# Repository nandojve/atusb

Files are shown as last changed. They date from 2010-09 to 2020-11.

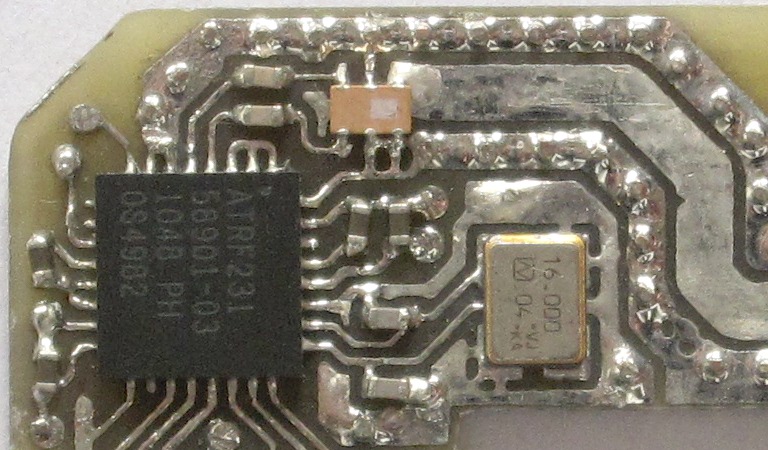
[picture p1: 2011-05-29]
prod/doc/atben-compor.jpg

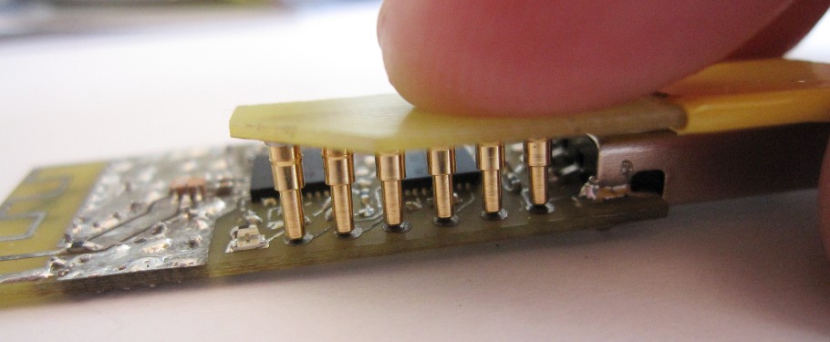
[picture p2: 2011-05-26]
prod/doc/atusb-programming.jpg

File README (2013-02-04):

IEEE 802.15.4 Low-Rate Wireless Personal Area Network (WPAN)
============================================================

IEEE 802.15.4 defines physical layers and a media access control for
wireless networks. ZigBee and 6loWPAN are based on IEEE 802.15.4.

This project aims to add experimental WPAN functionality to the Ben
NanoNote, in order to permit evaluation of overall network performance
and to examine possible integration into future devices.

This work is licensed under the terms detailed in the file COPYING.

Hardware history
----------------

IEEE 802.15.4 transceiver chips are available from several manufacturers,
including Atmel, Freescale, and Texas Instruments. These chips are similar
in size, functionality, and cost. The first prototype of this project was
based on the Atmel AT86RF230.

The initial plan was to place the RF module on the left side of the LCD
module of the Ben NanoNote, replacing part of the display's PCB. When
installed in the Ben, the transceiver would connect directly via SPI to
the Jz4720. For development, a SiLabs C8051F326 microcontroller
implemented a USB to SPI conversion.

Then Rikard Lindstrom came up with the idea of using the Ben's 8:10 card
slot as a general expansion interface, which led to the idea of making
a WPAN card in that form factor, with the benefit of being readily usable
with any Ben already in existence.

Thus the project was split in two parts: the atben card that had only the
transceiver chip and would be used with the Ben, and the atusb card that
would be similar to the original design but abandoned its clear physical
separation of USB and RF.

Meanwhile, an improved version of the AT86RF230, the AT86RF231, became
available and the designs were updated for it. It also turned out that
the clock from the Ben was too noisy to be used as a clock source for
the transceiver. Therefore, a crystal was added to the atben design.

Finally, the SiLabs C8051F326 was replaced by an ATmega32U2, mainly
because the latter has a larger Flash memory and greater community
acceptance.

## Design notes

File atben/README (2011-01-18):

PCB manufacturing:

- do not print PCB edges on front/back copper
- do not print component values on silk screen
- note that the transceiver is "upside down"
- the center (!) of the board edge line marks the true board edge, e.g.,

                             Edge line (5 mil)
                        =======
         ------- - - - - - ----------
               |           |
   PCB outside |           | PCB inside
               |           |
         ------- - - - - - ----------
                     |
               Volume removed when cutting
               (width depends on tool used)

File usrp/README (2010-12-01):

Antenna measurements
====================

The objective of antenna measurements is to determine how much energy the
antenna transfers at different frequencies. For this, we set up a sender,
a receiver, connect one to the antennas being tested, and the other to an
arbitrarily chosen lab antenna.

Since none of the items (sender, receiver, lab antenna) are calibrated,
we can only compare antennas but we cannot determine any absolute
characteristics.

Preparing a measurement run
---------------------------

Before measuring the characteristics of an antenna, we need to set up the
test environment and obtain a number of filtering parameters. The filters
are used to reduce the effect of noise on the measurements and to suppress
contamination from other sources.

1) Install transmitter and receiver. The transmitter is an atusb or atusd
   board, the receiver an USRP2+XCVR2450 with the antenna to test.

   (The same setup may also work with a USRP1 or UN210, and a RFX2400
   board.)

   Both should be spaced at least twenty times the wavelength (12.5 cm at
   2405 MHz), or 2.5 m apart. For test runs that can be compared with each
   other, antenna placement and orientation have to be exactly the same.

   The sender runs tools/atrf-txrx/atrf-txrx, the receiver runs utilities
   from gnuradio.

2) Obtain baseline performance values. For example, activate the sender
   with

   atrf-txrx -f 2455 -p 0.5 -T +0.5

   Emit a constant wave at 2455+0.5 MHz with a power of 0.5 dBm or 1.1 mW.

   Monitor the received signal with

   usrp2_fft.py -f 2455.5M -d 16

   Record the range in which the frequency peak falls. Variations of a few
   dB are to be expected.

3) Generate a series of sample for a specific setting.

   Example:

   The following script sets up the transmitter, lets it "warm up" for ten
   seconds, then takes 100 measurements, stored in files tmp00 through
   tmp99 in a directory $PWD/100/.

   In this setup, the receiver's gnuradio runs on a different host than
   the sender. Therefore we use ssh and pass the directory from $PWD.

    atrf-txrx -f 2455 -p 2.6 -T +0.5 \
      'sleep 10;
       for a in 0 1 2 3 4 5 6 7 8 9; do
         for b in 0 1 2 3 4 5 6 7 8 9; do
           ssh ws usrp2_rx_cfile.py -d 16 -f 2455.5M -g 46 -N 1124 \
	     '$PWD'/100/tmp$a$b
         done
       done'

   Each measurement obtains 1124 samples, 1024 samples for the FFT and
   100 samples to cut off (see below).

4) Determine the shape of the captured waves in the time domain, e.g.,
   with

   gnuplot
   gnuplot> plot "<./avg 1 <100/tmp00" with lines

   "avg" outputs the magnitude of the recorded wave, averaging over the
   specified number of sample.

   Some waves will probably show a peak in the first few samples. We need
   to cut off these peaks in the later processing steps. In this example,
   we will skip the first 100 samples.

   Besides the initial peak, the waves should be of comparable amplitude.

5) Verify the distribution in the frequency domain and determine the noise
   floor.

   gnuplot> plot "<./fft -s 100 -d <100/tmp00" with lines
                             ^
                          skip initial peak

   The spectrum should be U-shaped, with narrow peaks tens of dB above
   the noise floor near the beginning and the end. Note that the noise
   floor is curved and not perfectly flat.

   From this, we pick level of the noise floor. The value should be at or
   slightly below the highest peaks of the noise between the large peaks
   at the end of the spectrum.

   This noise floor value is used to filter uninteresting samples later
   on, removing a constant bias from the results.

   In this example, we'll use a noise floor value of -60 dB.

6) Determine the "interesting" frequency range. For this, we consider all
   the spectra of the measurements:

   gnuplot> plot "<for n in 100/tmp*; do ./fft -s 100 -d <$n;echo;done" \
     with lines

   There should be a thick noise band in the middle, with pronounced
   narrow peaks at the edges. If there are one or two signals on top of
   the noise band, some measurements have been compromised and need to be
   removed or redone. We will do this in the next step.

   When zooming into the left peak, the "bins" which contribute to the
   peaks can be identified. The range should be chosen with some
   tolerance, since the frequency may shift a bit during the measurement
   process.

   By not considering bins far from the peak, less noise is included in
   the final result, complementing the filtering by noise threshold from
   step 4). Restricting the bins also eliminates the second peak at the
   end of the spectrum.

   In this example, we'll use a range from 0 to 20.

7) Obtain the peaks from all measurements

   gnuplot> plot "<for n in 100/tmp*; do ./fft -s 100 0 20 60 <$n;done" \
     with lines
                                                   ^  ^  ^ ^
                                                   |  |  | |
                                   skip, from step 4  |  | threshold, 5)
                                             lowest bin  highest bin

   This should yield a jagged more or less horizontal line with values
   differing by not more than 1-2 dB. If there are any large outliers,
   they have been contaminated and should be dropped.

8) The final result for one measurement run can be obtained as follows:

   for n in 100/tmp*; do ./fft -s 100 0 20 60 <$n;done | ./range -v 2

   In this example, "range" eliminates all outliers more than 2 dB from
   the average and reports this.

   The output are three numbers: the average (after eliminating
   outliers), the minimum, and the maximum.

Performing a measurement run
----------------------------

The script "fscan" performs 100 scans of the 26 channels used by IEEE
802.15.4. The frequency scan is the inner loop, so that slow changes
in environmental parameters (background noise, temperature, etc.) will
affect the spread of the results over the entire frequency range instead
of causing seemingly frequency-dependent distortions.

The script is written for a setup that uses a pair of hosts, both
sharing the same file system.

Usage: fscan out-dir [tx-power]

The output directory must not exist yet. The transmit power is in dBm and
defaults to 2.6 dBm.

Example: ./fscan testant

The full run takes approximately half an hour.

The results are filtered and averaged by the script "evscan". This script
contains the filtering parameters obtained in the preparation, described
above.

Example: ./evscan testant >testant.out

The output is a graph with frequency, average signal strength, minimum
and maximum. The format is compatible with gnuplot's "with errorbars"
(or "with errorlines") plot style.

Finally, the results can be plotted with the script "plscan", which uses
gnuplot to output either in a window or to a PNG file.

Usage: plscan [-o pngfile] file ...

More than one graph can be plotted in the same run. The file name is used
as the title for each graph. Titles are truncated at the last dot.

Example: ./plscan testant.out

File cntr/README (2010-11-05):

Arbitrary-precision frequency counter
=====================================

Theory of operation
-------------------

The arbitrary-precision frequency counter counts clock cycles of a
frequency source that is assumed to be free from drift. It compares the
count with the host's system clock. If the system clock is synchronized
with an accurate NTP reference, measurements with arbitrarily high
accuracy can be obtained.

In practice, this is limited by the the frequency source's drift and
the time one is willing to wait. If NTP maintains the system time
with an accuracy of +/- 100 ms, obtaining measurements with an
accuracy of +/- 1 ppm would take about 28 hours.

Additional error sources, such as the round-trip time when requesting
a sample from the microcontroller, are also considered in the accuracy
calculation.

The counter consists of a board based on a C8051F320 microcontroller
and the control software on the host. The microcontroller counts
events in a free-running 16 bit counter that is regularly read and
extended to 32 bits. The 32 bit counter is periodically queried by
the host.

The microcontroller's counter can count at a frequency of up to 3 MHz.
(SYSCLK/4)

In order to protect against transmission errors not detected by USB's
CRC, which are occur relatively often, each packet is protected by a
CRC-32 and an inverted copy of the payload. Corrupted packets are
rejected by the host.

The 32 bit counter wraps around at most once very 21.8 ms. The 32 bit
counter wraps around at most every 1431 s. The host extends the 32 bit
counter to 64 bits, and calculates frequency and accuracy from the
count and the run time of the measurement application.

Performing a measurement
------------------------

To perform a measurement, connect the CNTR board's probe input to the
clock source and then run the "cntr" application on the host. An
accuracy goal (in ppm) can be specified on the command line (see
below).

The host polls the microcontroller every 100 ms and displays the run
time (in seconds), the measured frequency, and the accuracy achieved
so far.

Measurements can be stopped by pressing ^C or by specifying an
accuracy goal. At the end, the total number of events counted and
communication statistics are displayed.

Updating the firmware
---------------------

The protocol revision and the build date of the firmware of the CNTR
board can be queried with "cntr -i".

To update the firmware, run
cntr -r; sleep 1 && dfu-util -d 0x20b7:0xcb72 -D cntr.bin

Known issues (version 2 hardware)
---------------------------------

- the input circuit does not perform well. See ECN0006 for details.
- the MMCX connector is hard to solder because of its large thermal
  capacitance and surface
- the lateral pads of the MMCX connector could be wider
- manufacturing tolerances can push the USB connector a bit inside
  the board, making its signal pins overshoot the pads
- the ground fill under the LED causes a secondary cathode contact
  (which is harmless on this case)

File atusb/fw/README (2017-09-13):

Requires a very recent toolchain, because ATmega32U2 is relatively new.

- Building:

  make

- Uploading the firmware to a Ben (for flashing with the atusb-pgm cable):

  make HOST=<hostname> upload

  Example:

  make HOST=ben upload

  HOST defaults to "jlime".

- Flashing the boot loader:

  Prerequisite: avrdude on the Ben.

  Disconnect the atusb board from USB. Insert the atusb-pgm connector into
  the Ben. Place the atusb-pgm adapter on the exposed contact pads of the
  atusb board and push it down. Then run

  make prog

  This takes about 30 seconds. If the programming fails with an error
  message like "Yikes!  Invalid device signature.", verify that the
  atusb-pgm board is properly connected and placed, then try again.

- Uploading the application:

  Prerequisite: dfu-util installed on the PC.

  Insert atusb into the PC, then run

  make dfu

  Note: since the boot loader resets the USB bus after timing out,
  this operation can fail with a message like "No DFU capable USB device
  found". Just retry, and it will eventually get through.

HULUSB notes:
-------------
To prepare and flash the firmware on a HULUSB device some additional steps are
needed;

avr-objcopy -O ihex -R .signature -R .fuse -R .eeprom hulusb.elf hulusb.hex
dfu-programmer at90usb1287 flash hulusb.hex
dfu-programmer at90usb1287 reset

--------------------------

Making the toolchain:

# patches according to
# http://www.avrfreaks.net/index.php?name=PNphpBB2&file=viewtopic&p=789527

# some gcc prerequisites

apt-get remove avr-libc gcc-avr binutils-avr
apt-get install libmpfr-dev libmpc-dev

# binutils

wget http://ftp.gnu.org/gnu/binutils/binutils-2.21.tar.bz2
tar xfj binutils-2.21.tar.bz2 
cd binutils-2.21
./configure --target=avr --disable-nls
make
make install

# gcc

wget http://ftpmirror.gnu.org/gcc/gcc-4.5.2/gcc-4.5.2.tar.bz2
wget -O gcc_452_avr.patch http://gcc.gnu.org/bugzilla/attachment.cgi?id=23050
tar xfj gcc-4.5.2.tar.bz2
cd gcc-4.5.2
patch -p1 -s <../gcc_452_avr.patch
mkdir obj-avr
cd obj-avr
../configure --target=avr --enable-languages=c \
    --disable-nls --disable-libssp --with-dwarf2
make
make install

wget http://download.savannah.gnu.org/releases/avr-libc/avr-libc-1.7.1.tar.bz2
tar xfj avr-libc-1.7.1.tar.bz2 
cd avr-libc-1.7.1
./bootstrap	# the automake at the end takes a while
./configure --build=`./config.guess` --host=avr
make
make install

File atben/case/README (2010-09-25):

You'll need a working Heekscad [1] to open the cad file provided,
all file are licended under GPLv3

In kicad export/generate the PCB as gerber, note the extension is not .brd by default so you'll need to 
fix it manually to heekcad "see it".

Copyleft 2010 Cristian Paul Peñaranda  Rojas paul@kristianpaul.org

[1] http://code.google.com/p/heekscad/

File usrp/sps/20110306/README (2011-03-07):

Objective:

Reproduce sidebands observed in 200110303 and look for ways to reduce them.
In particular, examine the effect of the antenna tuning capacitor C16.

Test setup / changes:

4	original board, like in 20110303 (noise from WLAN I forgot to turn off)
4a	reflowed some RF vias; cleaning
4b	removed large solder deposits on RF; not cleaned
4c	cleaning after 4b
4d	0.5 pF at C16; cleaning
4e	1.0 pF at C16; cleaning
4f	C16 NC; cleaning
4g	resolder pin B1.1; cleaning
4h	replace cracked B1; switched to leaded solder; cleaning
4i	reflowed B1 at higher temperature; cleaning
4j	reflowed C8's balun side; cleaning

3	original board, like in 20110303
3a	wait 2 h (warm-up; USRP2 freshly booted)
3b	cycle (unplug/plug) atusb
3c	retract shutters (metal)

-------------------------------------------------------------------------------

Observations:

4	behaves as it did in 20110303
4a	no change
4b	no change
4c	no change
4d	no change
4e	no change
4f	major regression
4g	regression persists
4h	regression persists (slight recovery seen in 4h-0 may be due to
	temporary effects)
4i	regression persists
4j	regression persists; giving up

3	behaves as it did in 20110303; significantly cleaner
3a	sidebands are reduced
3b	sideband reduction persists
3c	~10 dB drop at lower end of spectrum

-------------------------------------------------------------------------------

Conclusions:

- build quality seems to be principal factor in RF performance variations
- a warmed up board performs slightly better than a cold board
- C16 has no noticeable effect
- reflection characteristics even of distant items in the environment have
  a strong influence on relative signal strength

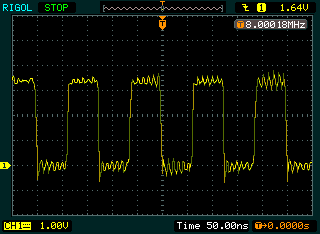
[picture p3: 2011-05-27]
prod/doc/scope-atusb-clkm.png

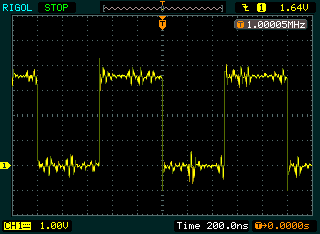
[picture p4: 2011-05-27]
prod/doc/scope-atben-clkm.png

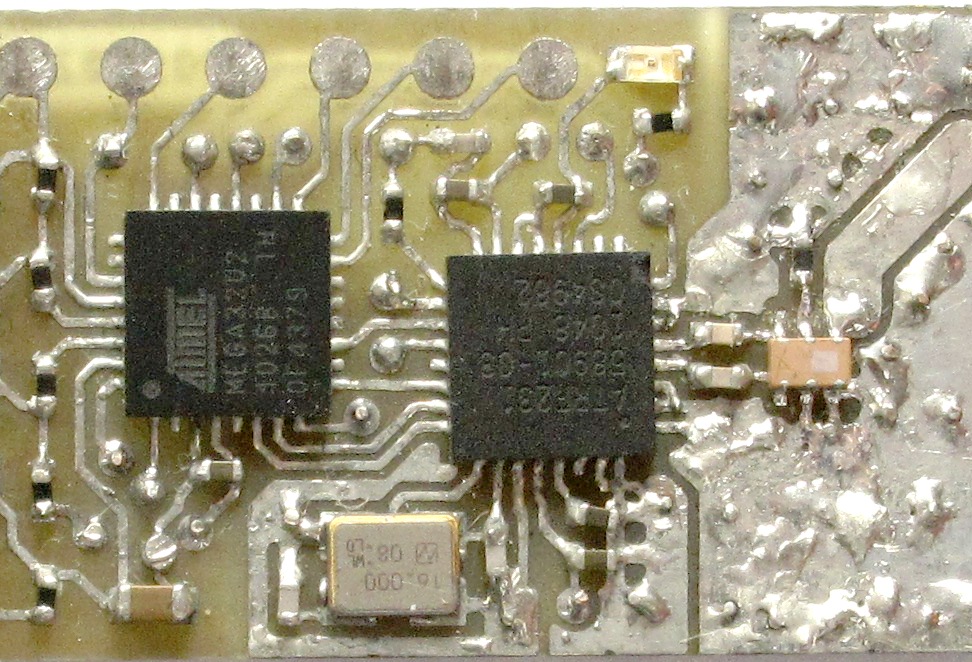
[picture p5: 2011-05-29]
prod/doc/atusb-compor.jpg

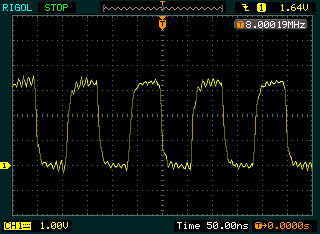
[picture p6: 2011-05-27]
prod/doc/scope-atusb-clk.png

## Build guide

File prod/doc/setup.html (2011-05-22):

# Production and testing: Software setup

Before performing any production tests, various pieces of software need to be installed on Ben and PC, and configuration settings @@@

## PC software installation

@@@

### Install ben-wpan tools

@@@

### Install test scripts

@@@

### Install firmware binary

The binary of the application running on atusb is transferred from the PC. To download a pre-compiled version, use this command:

wget -O atusb.bin \
     http://downloads.qi-hardware.com/people/werner/wpan/bindist/atusb-de72af351f661b538add81cbc9965278a2f8c40c.bin

Instructions for building the binary from sources are here (http://projects.qi-hardware.com/index.php/p/ben-wpan/source/tree/master/atusb/fw/README).

### Register Ben host name

To simplify accessing the Ben via TCP/IP, its IP address should be registered in the hosts file on the PC. If the Ben is running OpenWrt, use the following command:

echo 192.168.254.101 ben >>/etc/hosts

If the Ben is running Jlime, the address would be as follows:

echo 192.168.1.202 ben >>/etc/hosts

If using the same PC with Bens running OpenWrt and Jlime, one may choose different host names depending on the distribution, and adapt the commands used in the production and testing process accordingly. For example,

echo 192.168.254.101 ben >>/etc/hosts
echo 192.168.1.202 jlime >>/etc/hosts

### Customize test scripts

@@@

## Ben software installation

@@@

### Password-less remote access

To enable password-less remote access from the PC, set up network access to the Ben and run the following command:

ssh ben 'cat >>/etc/dropbear/authorized_keys' <~/.ssh/id_rsa.pub

### Install ben-wpan tools

@@@

### Install avrdude

The atusb boot loader is flashed using avrdude. A pre-compiled static binary (suitable for OpenWrt and Jlime) can be installed by running the following two command on the Ben:

wget http://downloads.qi-hardware.com/people/werner/wpan/bindist/avrdude-5.10-de72af351f661b538add81cbc9965278a2f8c40c.tar.gz
tar -xz -C / -f avrdude-5.10-de72af351f661b538add81cbc9965278a2f8c40c.tar.gz

Instructions for building avrdude from sources are here (http://projects.qi-hardware.com/index.php/p/ben-blinkenlights/source/tree/master/avrdude/README).

### Install boot-loader binary

The binary of the boot loader running on atusb is transferred from the Ben. To download a pre-compiled version, use this command:

wget -O boot.hex \
   http://downloads.qi-hardware.com/people/werner/wpan/bindist/boot-de72af351f661b538add81cbc9965278a2f8c40c.hex

Instructions for building the binary from sources are here (http://projects.qi-hardware.com/index.php/p/ben-wpan/source/tree/master/atusb/fw/README).

## Ben system setup

The configuration setting described in this section are lost on each reset or reboot and either need to be entered again. Alternatively, a setup script running at boot time can be written.

### Enable network access

Once the Ben has booted and started USB networking, the interface on the PC side is configured as follows:

ifconfig usb0 192.168.254.100 up

These are the settings for OpenWrt, assuming the network device is called "usb0". If using Jlime, the command would be as follows:

ifconfig usb0 192.168.1.200 up

### Silence other 8:10 card users

Before running any of the ben-wpan utilities, other users of the 8:10 card slot have to be disabled. In a Ben running the regular OpenWrt or Jlime distribution, the only such user that is automatically started is the MMC kernel driver. The following command disables it:

echo jz4740-mmc.0 >/sys/bus/platform/drivers/jz4740-mmc/unbind

If a WPAN-enabled kernel has been installed, the AT86RF230 driver takes the place of the MMC driver. To disable it, run

echo spi2.0 >/sys/bus/spi/drivers/at86rf230/unbind

### Start atrf-proxy

On the Ben, launch the proxy daemon. We pass the option -b to background it:

atrf-proxy -b

## Test profiles

Some of the functional tests measure characteristics that are strongly influenced by the test setup. It is therefore not possible to provide universally applicable reference values, but they have to be measured in the actual test environment.

### Clock count (atben only)

Insert a known to be good atben board and run the following command directly on the Ben to record the reference value for the clock count with an accuracy of about +/−20 ppm:

atrf-xtal 1000 >ben.xtal

This takes about 5 seconds.

Note that the result depends on the tolerance of the crystal in the Ben and is also affected by temperature. Good accuracy can therefore only be obtained if this measurement is performed individually on each Ben, and if a stable temperature is maintained.

### Signal strength

@@@

Up: Production and testing Next: Flashing (atusb only)

Last update: 2011-05-19 Werner Almesberger

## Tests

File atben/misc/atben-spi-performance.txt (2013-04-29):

Performance analysis of SPI drivers for ATBEN
=============================================

This was originally posted on April 10 2013 to the linux-zigbee and
the qi-hardware list. The URLs have been updated for stability.

Note that the code referenced in this analysis is meant to illustrate
the general concepts. Some variants have been dropped since and the
ones still in existence have been cleaned up and debugged in
preparation for upstream submission. The current versions can be
found in https://github.com/wpwrak/ben-wpan-linux

What this is all about
----------------------

The ATBEN board on the Ben NanoNote needs a bit-banging SPI driver.
There are several ways to implement this, ranging from reuse of the
generic spi-gpio driver to an optimized driver that's specific for
this platform.

I implemented several such approaches and measured their performance
in the Ben NanoNote. Below are my findings.

Comments welcome.

Cast and characters
-------------------

spi_atben_gpio: NanoNote-specific framework for setting up the
AT86RF230/1 with SPI-GPIO or one of the optimized drivers (below).
The name derives from spi_atben (see below) and should be changed
(maybe to atben_spi or atben_spi_gpio ?) since it is not an SPI
driver but merely a framework that provides configuration data and
performs miscellaneous platform setup.
https://github.com/wpwrak/ben-wpan-linux/blob/perfcomp/drivers/net/ieee802154/spi_atben_gpio.c

spi_atben: like spi_atben_gpio, but contains a highly optimized
SPI driver for the ATBEN configuration in the Ben NanoNote.
https://github.com/wpwrak/ben-wpan-linux/blob/perfcomp/drivers/net/ieee802154/spi_atben.c

spi-jz4740-gpio: SPI-GPIO driver optimized for the Jz4740. Uses the
optimized register accesses from spi_atben but pin assignment is not
restricted to ATBEN. The only limitation is that MOSI, MISO, and
SCLK must be on the same port.
https://github.com/wpwrak/ben-wpan-linux/blob/perfcomp/drivers/spi/spi-jz4740-gpio.c

spi-gpio-atben: task-specific SPI-GPIO driver using the #include
"spi-gpio.c" method. Replaces gpiolib functions with register
accesses specific to the ATBEN configuration in the Ben NanoNote.
Note that some of the code could be moved into Jz4740
architecture-specific GPIO support.
https://github.com/wpwrak/ben-wpan-linux/blob/perfcomp/drivers/spi/spi-gpio-atben.c

In the following sections, we abbreviate the stack configurations
as follows:

Abbreviation	Framework	Transport	Chip driver
---------------	---------------	---------------	-----------
spi-gpio	spi_atben_gpio	spi-gpio	at86rf230
spi-gpio-atben	spi_atben_gpio	spi-gpio-atben	at86rf230
spi-jz4740-gpio	spi_atben_gpio	spi-jz4740-gpio	at86rf230
spi_atben	spi_atben			at86rf230

Measurements
------------

Access time to AT86RF231 registers and buffer, in microseconds, on
an otherwise idle Ben NanoNote:

Driver		read from 0x51		read 120 bytes from buffer
|		|	write 0x0a to 0x15	write 1 byte to buffer (0x33)
|		|	|	read 1 byte from buffer	write 120 bytes
|		|	|	|	|	|	|
spi-gpio	 81	 85	186	1696	 97	1596
spi-gpio-atben	 63	 59	123	 498	 65	 437
spi-jz4740-gpio	 10	  8	 21	 280	 10	 231
spi_atben	 10	  7	 21	 280	 10	 230

Data rate for hypothetical buffer accesses of infinite length.
I.e., kbps = 1000*119*8/(t_write120-t_write1)

Driver		buffer read (kbps)	buffer write (kbps)
---------------	-----------------------	-------------------
spi-gpio	 630			 635			
spi-gpio-atben	2549			2559
spi-jz4740-gpio	3676			4308
spi_atben	3676			4327

At the air interface, IEEE 802.15.4 has a data rate of 250 kbps.
The AT86RF231 transceiver also supports non-standard higher data
rates up to 2 Mbps.

Driver(s)				Code size (lines)
---------------------------------------	-----------------
spi_atben_gpio				 128
spi_atben_gpio + spi-gpio-atben		 128+ 53
spi_atben_gpio + spi-jz4740-gpio	 128+416
spi_atben				 423

Computational cost
------------------

The high-level operations of sending and receiving produce the
following major low-level operations:

Operation	register	buffer		waitqueue
		read	write	read	write
---------------	-------	-------	-------	-------	---------
reception	1	-	1	-	1
transmission	9	4	-	1	1

Using the measured data from above, we get the following total
computational overhead in microseconds, without considering the
waitqueue scheduling delay:

Driver		reception		transmission
		1	120	127	1	120	125 (bytes)
---------------	-------	-------	-------	-------	-------	-------
spi-gpio	 267	1777	1866	1166	2665	2727
spi-gpio-atben	 186	 561	 583 	 868	1240	1256
spi-jz4740-gpio	  31	 290	 304 	 132	 353	 362

Note that the minimum frame length in IEEE 802.15.4 is 5 bytes.
The values for 125 (excluding CRC) and 127 (including CRC) bytes
are extrapolated.

According to [1], maximum-sized frames can be sent/received,
including CSMA/CA and acknowledgement, at a rate between one
every 4928 us and one every 7168 us.

We would therefore get the following maximum CPU load:

Driver		Reception	Transmission
---------------	---------------	------------
spi-gpio	38%		55%
spi-gpio-atben	12%		25%
spi-jz4740-gpio	 6%		 7%

Observations
------------

spi-gpio needs the smallest amount of new code but is also very
inefficient, making it questionable whether this configuration
would yield acceptable performance in regular use.

With spi-gpio-atben, only a small amount of code is added, but
buffer accesses become almost 4 times faster. Register reads and
writes are still fairly slow.

spi_atben and spi-jz4740-gpio both achieve the best performance
without significant differences between them. Both add a complete
SPI driver. Of the two, spi-jz4740-gpio is preferable, because it
uses the nearly universal spi_atben_gpio framework driver.

Conclusion
----------

I think performance trumps most other considerations in this case.
spi-gpio is clearly too inefficient. spi_atben_gpio with
spi-jz4740-gpio offers the best performance and has a low impact
on the system load (< 10%). In case this solution would be met
with strong resistance for some reason, spi-gpio-atben would offer
a compromise between performance and the amount of code.

References
----------

[1] http://www.jennic.com/files/support_files/JN-AN-1035%20Calculating%20802-15-4%20Data%20Rates-1v0.pdf

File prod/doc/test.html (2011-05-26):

# Production and testing: Functional test

## Test setup for atben

To test an atben board, place a reference atusb board into the PC, insert the



## Test setup for atusb



## Test procedure

The test process is started with

make ben

for an atben DUT and with

make usb

for an atusb DUT. It performs the following steps:

- Enumeration (atusb only)
- LED (atusb only; not yet implemented)
- GPIO scan (not yet implemented)
- Identification
- Crystal frequency (only implemented on atben)
- Spectrum
- Receive
- Send

Of these tests, only "LED" and "Spectrum" require operator input. The other tests run without interaction.

The test scripts log the commands they execute and their output in the file _log.

### Enumeration (atusb only)

The enumeration test verifies that the atusb board has been identified by the PC's USB stack. If this test fails, the board may not be plugged in correctly or it may be missing the firmware. A board that has passed both stages of the firmware flashing process should always pass the enumeration test.

### LED (atusb only)

@@@

### GPIO scan

@@@

### Identification

This test reads the transceiver's registers that contain values identifying the manufacturer, the chip's part number, and the chip revision. If an atusb board fails this test, this probably means that the MISO signal between transceiver and the microcontroller has a problem.

On atben, failure may simply indicate an improperly inserted board. Eject the board, re-insert, and try again. If the test keeps on failing, this may indicate a problem with MOSI, MISO, nSEL, SCLK, the power supply, the crystal oscillator, or possibly the position of the transceiver chip.

Note: this test is meant as a higher level test. The GPIO test should eventually provide more detailed results for problems with the SPI interface.

### Crystal frequency (atben only)

This test measures the frequency of the crystal oscillator in the DUT. On atben, it does this by transmitting packets, and measuring the time between the SLP_TR pulse that starts the transmission and the interrupt signaling the end of the transmission.

If this test fails, this may indicate that the load capacitors of the crystal are missing, badly soldered, or have the wrong value. It could also mean that the crystal itself is defective. Another possible cause of oscillator malfunction could be flux residues bridging traces.

The fault analysis page has more details on testing the crystal oscillator.

### Spectrum

The spectrum test measures the reception of a signal sent from the reference device to the DUT. It does this across the entire frequency range in which the WPAN boards operate, allowing the detection of frequency-dependent anomalies.

This test depends on numerous external factors, like the exact position and orientation of the two devices with respect to each other, and the presence of any items that can reflect or absorb RF signals. Such items include metal chairs and human bodies. Because of the test's sensitivity to environmental factors, the operator needs to decide when the result represents a valid measurement and then confirm the result shown.

The image below shows the typical display during the spectrum test: the white line is the measured signal strength. The red lines indicate the minimum and maximum allowed values. The green circle in the upper right corner indicates that the signal strength is within the limits. A downward-pointing red triangle would indicate that the signal is too weak, an upward-pointing yellow triangle would indicate that the signal is too strong.



To finish the test, the operator must type either P, F, or Q in the window shown. P means "pass" and can only be entered if the measurement is within the limits. F means "fail" and can only be entered if the measurements is outside the limits. Q, quit, can be entered at any time and also fails the test.

### Receive

In the receive test, the reference device sends a number of frames to the DUT. The test program verifies correct reception of all the frames. A device that has passed all the preceding tests should not encounter problems in the receive test. If it does, there may be a problem with the bypassing of the transceiver's 1.8 V supplies.

### Send

The send test is like the receive test, but with the DUT acting as the sender and the reference acting as the receiver. If a device passes the receive test but fails the send test, there is probably an issue with the bypass capacitors of the analog 1.8 V supply.

Another possible cause could a problem with the SLP_TR signal. The GPIO test should eventually catch this issue, but it may currently remain undetected until the send test.

Up: Production and testing Prev: Flashing (atusb only) Next: Fault analysis

Last update: 2011-05-26 Werner Almesberger

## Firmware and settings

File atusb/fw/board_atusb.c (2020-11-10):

/*
 * fw/board_atusb.c - ATUSB Board-specific functions (for boot loader and application)
 *
 * Written 2016 by Stefan Schmidt
 * Copyright 2016 Stefan Schmidt
 *
 * This program is free software; you can redistribute it and/or modify
 * it under the terms of the GNU General Public License as published by
 * the Free Software Foundation; either version 2 of the License, or
 * (at your option) any later version.
 */


#include <stdbool.h>
#include <stdint.h>

#include <avr/io.h>
#include <avr/interrupt.h>
#include <avr/boot.h>

#define F_CPU   8000000UL
#include <util/delay.h>

#include "usb.h"
#include "at86rf230.h"
#include "board.h"
#include "spi.h"
#include "usb/usb.h"

static bool spi_initialized = 0;

void reset_rf(void)
{
	/* set up all the outputs; default port value is 0 */

	DDRB = 0;
	DDRC = 0;
	DDRD = 0;
	PORTB = 0;
	PORTC = 0;
	PORTD = 0;

	OUT(LED);
	OUT(nRST_RF);   /* this also resets the transceiver */
	OUT(SLP_TR);

	spi_init();

	/* AT86RF231 data sheet, 12.4.13, reset pulse width: 625 ns (min) */

	CLR(nRST_RF);
	_delay_us(2);
	SET(nRST_RF);

	/* 12.4.14: SPI access latency after reset: 625 ns (min) */

	_delay_us(2);

	/* we must restore TRX_CTRL_0 after each reset (9.6.4) */

	set_clkm();
}

void led(bool on)
{
	if (on)
		SET(LED);
	else
		CLR(LED);
}

void set_clkm(void)
{
	/* switch CLKM to 0 MHz */

	/*
	 * @@@ Note: Atmel advise against changing the external clock in
	 * mid-flight. We should therefore switch to the RC clock first, then
	 * crank up the external clock, and finally switch back to the external
	 * clock. The clock switching procedure is described in the ATmega32U2
	 * data sheet in secton 8.2.2.
	 */
	spi_begin();
	spi_send(AT86RF230_REG_WRITE | REG_TRX_CTRL_0);
	spi_send(CLKM_CTRL_OFF);
	spi_end();
}

void board_init(void)
{
	/* Disable the watchdog timer */

	MCUSR = 0;		/* Remove override */
	WDTCSR |= 1 << WDCE;	/* Enable change */
	WDTCSR = 1 << WDCE;	/* Disable watchdog while still enabling
				   change */

	CLKPR = 1 << CLKPCE;
	/* We start with a 1 MHz/8 clock. Disable the prescaler. */
	CLKPR = 0;

	get_sernum();
}

void spi_begin(void)
{
	if (!spi_initialized)
		spi_init();
	CLR(nSS);
}

void spi_off(void)
{
	spi_initialized = 0;
	UCSR1B = 0;
}

void spi_init(void)
{
	SET(nSS);
	OUT(SCLK);
	OUT(MOSI);
	OUT(nSS);
	IN(MISO);

	UBRR1 = 0;	/* set bit rate to zero to begin */
	UCSR1C = 1 << UMSEL11 | 1 << UMSEL10;
			/* set MSPI, MSB first, SPI data mode 0 */
	UCSR1B = 1 << RXEN1 | 1 << TXEN1;
			/* enable receiver and transmitter */
	UBRR1 = 0;	/* reconfirm the bit rate */

	spi_initialized = 1;
}

void usb_init(void)
{
	UHWCON |= 1 << UVREGE;		/* Power-On USB pad regulator */
	USBCON |= 1 << FRZCLK;		/* freeze the clock */

	/* enable the PLL and wait for it to lock */
	PLLCSR &= ~(1 << PINDIV);
	PLLCSR |= 1 << PLLE;
	while (!(PLLCSR & (1 << PLOCK)));

	USBCON &= ~(1 << USBE);		/* reset the controller */
	USBCON |= 1 << USBE;

	USBCON &= ~(1 << FRZCLK);	/* thaw the clock */

	USBCON |= 1 << OTGPADE;

	while (!(USBSTA & (1 << VBUS)));

	UDCON &= ~(1 << DETACH);	/* attach the pull-up */
	UDIEN = 1 << EORSTE;		/* enable device interrupts  */
//	UDCON |= 1 << RSTCPU;		/* reset CPU on bus reset */

	ep_init();
}

void board_app_init(void)
{
	/* enable INT0, trigger on rising edge */
	EICRA = 1 << ISC01 | 1 << ISC00;
	EIMSK = 1 << 0;
}

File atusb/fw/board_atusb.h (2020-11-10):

/*
 * fw/board_atusb.h - ATUSB Board-specific functions and definitions
 *
 * Written 2016 by Stefan Schmidt
 * Copyright 2016 Stefan Schmidt
 *
 * This program is free software; you can redistribute it and/or modify
 * it under the terms of the GNU General Public License as published by
 * the Free Software Foundation; either version 2 of the License, or
 * (at your option) any later version.
 */

#ifndef BOARD_ATUSB_H
#define	BOARD_ATUSB_H

#include <stdbool.h>
#include <stdint.h>

#define	LED_PORT	B
#define	LED_BIT		  0
#define	nRST_RF_PORT	C
#define	nRST_RF_BIT	  6
#define	SLP_TR_PORT	D
#define	SLP_TR_BIT	  7

#define SCLK_PORT	D
#define SCLK_BIT	  5
#define	MOSI_PORT	D
#define	MOSI_BIT	  3

#define	MISO_PORT	D
#define	MISO_BIT	  2
#define	nSS_PORT	D
#define	nSS_BIT		  1
#define	IRQ_RF_PORT	D
#define	IRQ_RF_BIT	  0

#define SPI_WAIT_DONE()	while (!(UCSR1A & 1 << RXC1))
#define SPI_DATA	UDR1

void set_clkm(void);
void board_init(void);

void spi_begin(void);
void spi_off(void);
void spi_init(void);

#endif /* !BOARD_H */

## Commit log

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2010-08-12 Updated the LED.
    - BOOKSHELF: added LTST-C190KRKT data sheet
    - usb.sch: changed R1 to 68 Ohm. C8051F326 VOH at -10 mA is typ.
    VIO-0.8 V = 2.5 V, the LTST-C190KRKT has Vf at 10 mA typ. ~1.8 V
    (fig. 2), so we need to burn about 0.7 V.
    - usb.sch: set the value of VR1, VR2, VR3 (add more details later)
    [usb.sch]
2010-08-12 usb.sch cleanup.
    - usb.sch: labeled D+ and D- nets
    - usb.sch: moved VDD to avoid connected cross intersection
    [usb.sch]
2010-08-13 First layout draft. (No GND areas, not quite following design rules.)
    - wpan-atrf.brd: first attempt at a layout for the USB prototype
    - wpan-atrf.cmp: (redundant) component list, to keep pcbnew from complaining
    - atrf.sch: added labels to previously anonymous nets
    - wpan-atrf.pro: added libraries (and noise from cvpcb and pcbnew)
    [atrf.sch, wpan-atrf.brd]
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2010-08-13 More board cleanup.
    - wpan-atrf.brd: rearranged ground areas to prevent sections from being
    cut off
    - wpan-atrf.brd: on PCB, added descriptive text, chip orientation, and
    version
    [wpan-atrf.brd]
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2010-08-18 Net name correction, layout update.
    - atrf.sch: typo: CLKN net is really CLKM, like the signal driving it
    - wpan-atrf.brd: updated layout for VBUS/VDD correction
    - wpan-atrf.brd: set date code to "100818"
    [atrf.sch, wpan-atrf.brd]
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2010-08-20 A new try at config.h management: moved it to ../common, along with io.h
    - fw/boot/Makefile, fw/atspi/Makefile: add ../common to include path
    - fw/boot/config.h, fw/atspi/io.h: moved to ../common
    - fw/common/config.h: updated comment - it's no longer specific to boot.c
    [io.h]
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2010-08-20 Implemented AT86RF230 reset and access modes. (Completely untested.)
    - fw/atspi/at86rf230.h: AT86RF230 SPI protocol commands and buffer sizes
    - fw/atspi/atspi.c (init_io): set all IOs to their initial state
    - fw/include/atspi/ep0.h, fw/atspi/ep0.c (my_setup): command ATSPI_RF_RESET
    to reset the AT86RF230
    - fw/include/atspi/ep0.h, fw/atspi/ep0.c (my_setup): commands
    ATSPI_{REG,BUF,SRAM}_{READ,WRITE} for the six SPI access modes
    [at86rf230.h, ep0.c]
2010-08-20 Simplified the presentation of build date information and added a command-line utility to retrieve it.
    - fw/include/atspi/ep0.h, fw/atspi/ep0.c (my_setup): merged
    ATSPI_BUILD_NUMBER and ATSPI_BUILD_DATE into single ATSPI_BUILD
    - fw/atspi/ep0.c (my_setup): added work-arounds for compiler bugs
    - tools/atspi-id/Makefile, tools/atspi-id/atspi-id.c: command-line utility
    to query hardware and firmware version
    [ep0.c]
2010-08-20 Active-high IRQ_RF was routed to active-low interrupt input
    - usb.sch: route IRQ_RF to INT0, not nINT0
    - wpan-artf.brd: updated layout and date code
    - wpan-atrf.pro, wpan-atrf.sch, atrf.sch: KiCad update noise
    [atrf.sch, usb.sch, wpan-atrf.brd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]
2010-08-20 xxx_MODE were used as if they were port bits, not registers.
    - fw/atspi/atspi.c (init_io): comment had the wrong initial value for SCLK
    - fw/atspi/atspi.c (init_io): xxx_MODE are registers, not bits ...
    - fw/common/io.h (IRQ_RF), fw/atspi/atspi.c (init_io): indicate pending
    moving of IRQ_RF
    [io.h]
2010-08-21 We can now read the transceiver's registers.
    - fw/atspi/atspi.c (init_io, reset_rf): reset the transceiver after setting
    up the IOs. Contrary to what the manual claims, the chip only produce
    garbage if not reset.
    - fw/atspi/ep0.c (my_setup): call reset_rf instead of open-coding the reset
    - fw/atspi/atspi.c (init_io): added #ifdef'ed-out code to disable the
    pull-ups, and an explanation why we can't do this.
    - tools/atspi-id/atspi-id.c (show_info): also read and print the
    transceiver's ID registers
    [ep0.c]
2010-08-21 Enter TRX_OFF to enable DVDD regulator. Plus minor cleanup.
    - tools/atspi-txrx/Makefile, tools/atspi-txrx/atspi-txrx.c: new utility
    that, for now, just turns on the DVDD regulator
    - tools/atspi-id/Makefile: corrected path in title
    - fw/include/at86rf230.h: changed TRX_STATE_* to TRX_CMD_*
    [at86rf230.h]
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2010-08-23 Moved fw/ and tools/ into atrf/ as well.
    - fw/: moved to atrf/fw/
    - tools/: moved to atrf/tools/
    - atrf/fw/atspi/Makefile, atrf/fw/boot/Makefile: updated relative path to
    f32xbase
    - atrf/tools/Makefile: updated relative path to Makefile.recurse
    - atrf/tools/atspi-id/Makefile, atrf/tools/atspi-reset/Makefile,
    atrf/tools/atspi-rssi/Makefile, atrf/tools/lib/Makefile: updated relative
    path to f32xbase
    - atrf/fw/include/at86rf230.h: corrected path in title
    - atrf/tools/include/atspi.h: added title and copyright header
    [at86rf230.h]
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2010-08-24 Update IRQ_RF after reworking both boards. IRQ_RF was erroneously connected to P0_2 but it should go to P0_0.
    - atrf/fw/common/io.h: IRQ_RF is now at P0_0
    - atrf/fw/atspi/atspi.c: updated and simplified P0 initialization
    [io.h]
2010-08-24 Finished and tested TX/RX. (LQ doesn't work yet, the rest does.)
    - Makefile.recurse (all): reorder DIRS and TARGET_ONLY_DIRS, so that
    tools/lib/ gets built before the tools that depend on it
    - atrf/fw/atspi/ep0.c (do_buf_write): removed duplicate sending of
    AT86RF230_BUF_WRITE
    - atrf/fw/atspi/ep0.c (my_setup): generate the PHR in ATSPI_BUF_WRITE
    instead of expecting the host to send it
    - atrf/fw/atspi/ep0.c (my_setup): don't send the PHR to the host in
    AT86RF230_BUF_READ
    - atrf/fw/include/at86rf230.h (REG_TR_PWR): should be REG_PHY_TX_PWR
    - atrf/tools/Makefile: added atspi-txrx and "lib"
    - atrf/tools/atspi-txrx/Makefile: corrected path in F32XBASE
    - atrf/tools/atspi-txrx/atspi-txrx.c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
    [at86rf230.h, ep0.c]
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2010-08-25 Made communication with CNTR board more robust. Added documentation.
    - cntr/README: description of the counter board and its application
    - cntr/fw/common/crc32.c: variant of CRC32-IEEE802.3 shared by firmware and
    measurement application
    - cntr/fw/cntr/ep0.c (my_setup), cntr/tools/cntr/cntr.c (get_sample):
    protect the counter value with a CRC and an one's complement copy
    - cntr/fw/include/cntr/ep0.h: oops, wasn't checked into repository
    - cntr/tools/cntr/cntr.c: added section titles
    - cntr/tools/cntr/cntr.c (measure): show communication statistics at the end
    - cntr/tools/cntr/cntr.c (measure, usage, main): new option -d to enable
    reporting of communication errors
    - cntr/tools/cntr/cntr.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
    [ep0.c]
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2010-08-26 Populated load capacitors of the crystal. Started organizing issues in ECNs.
    - atrf/ecn/INDEX: ECN index
    - atrf/ecn/ecn0001.txt: Adjust balun component values (pending)
    - atrf/ecn/ecn0002.txt: Add load capacitors to 16 MHz crystal (C14, C15)
    - atrf.sch, atrf/wpan-atrf.brd: changed load capacitors from NC to 12 pF
    - atrf/ecn/ecn0003.txt: Replace balun and filter with integrated balun
    (pending)
    - TODO: one more CNTR-related task
    [atrf.sch, wpan-atrf.brd]
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2010-09-03 Assorted small layout improvements.
    - atusd/atusd.brd: tightened routing of nSS and XTAL1 net to improve ground
    place coverage
    - modules/0805-6.fpd: widened pads for easier manual soldering (note: this
    is still ad hocery)
    - atusd/atusd.brd: use thinner track to connect feed line to comply with
    DRC
    - atusd/atusd.brd: version is now 100903
    [atusd.brd]
2010-09-05 First part of the board bringup: power and clock.
    - atusd/ERRATA: variations of the circuit being debugged from the design
    - tools/Makefile, tools/try.c, tools/lib/atusd.c: user-space tool to enable
    the board and (in the future) establish communication
    - atusd/sim/clk.sch: simulation of CLK attenuation circuit with capacitative
    load from scope probe
    [clk.sch]
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2010-09-08 Found out that we can't share MISO and MOSI after all. Redesigned the atusd board.
    - atusd/atusd.sch, atusd/atusd.brd: separate MISO and MOSI and free the
    extra signal we need by no longer connecting SLP_TR to the host
    - atusd/atusd.sch, atusd/atusd.cmp, atusd/atusd.brd: removed reset circuit
    Power-on reset seems to be sufficient.
    - atusd/atusd.brd: improved AVDD ground plane
    - cam/pcb.pl (rot): cut counter-clockwise to reduce burr
    - cam/pcb.pl: advanced origin for 2nd run
    [atusd.brd, atusd.sch]
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2010-09-09 Improved clock stability by using a capacitative divider and found more minor issues.
    - atusd/ERRATA: work around the clock instability by replacing the
    resistive divider with a capacitative divider
    - atusd/ERRATA: a ground plane under the clock circuit would also be good to
    have
    - atusd/ERRATA: via near pin 1 is too close to the chip if we need to cut
    wires (in DIY boards)
    - atusd/sim/cdiv.sch: simulation of the capacitative divider
    [cdiv.sch]
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2010-09-11 Applied clock voltage divider fix and corrected too closely spaced via.
    - atusd/atusd.sch, atusd/atusd.cmp, atusd/atusd.brd: changed resistive
    clock voltage divider to capacitative
    - atusd/atusd.brd: moved via near pin 1 and rearranged ground planes
    accordingly
    - atusd/atusd.sch, atusd/atusd.brd: bumped version number to 20100911
    - atusd/atusd.pro: KiCad commit noise
    [atusd.brd, atusd.sch]
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2010-09-12 Corrected small footprint errors. Made 0R "inductor" a resistor.
    - atusd/atusd.sch, atusd/atusd.cmp, atusd/atusd.brd: made L1 a resistor
    - atusd/atusd.sch, atusd/atusd.cmp, atusd/atusd.brd: changed effective
    footprints of components erroneously using 0805 to 0805-M
    - atusd/atusd.pro: commit noise
    [atusd.brd, atusd.sch]
2010-09-12 Added antenna tuning "tail" suggested by Joerg. Made board slimmer.
    - modules/meander.fpd, atusd/atusd.brd: added tuning "tail" to antenna
    (suggested by Joerg Reisenweber)
    - atusd/atusd.brd: pulled back somewhat protruding CLKM test point
    - atusd/atusd.brd: made external board 20 mil narrower
    - atusd/atusd.brd: version number is now 20100912
    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
    [atusd.brd]
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2010-10-24 Assorted termination simulation cleanup.
    - term/Makefile: "make qucs" shortcut for invoking qucs
    - term/term.sch: disable switch to .dpl page after simulation
    - term/term.sch: changed R3 from 50 Ohm to the more common 47 Ohm
    - term/term.sch: changed C2 from 22 pF to 330 pF to match TVS
    - term/term.sch: renamed Vin to Vdst and put graph in diagram on top
    - term/term.sch: added more annotations
    [term.sch]
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2010-10-25 Revert TVS size reduction. We're not ready for it yet.
    - cntr/cntr.sch (VR1, VR2, VR3): reverted change to 0402, because this
    would be too difficult to route with current board
    - cntr/cntr.sch (VR1, VR2, VR3): change voltage from 5.6 V to 5.5 V,
    for compatibility with selected part
    - cntr/cntr.brd: updated for value change
    [cntr.brd, cntr.sch]
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2010-10-25 Cleanup of values in atusb/*.sch
    - atusb/atrf.sch (C6, C7): use canonical name 820fF instead of 0.82pF
    - atusb/usb.sch (VR1, VR2, VR3): changed value from 5V6 to 5V5 for
    compatibility with selected part
    - atusb/atusb.sch: commit noise
    - atusb/atusb.brd: reloaded for value changes
    [atrf.sch, atusb.brd, atusb.sch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]
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2010-10-25 Major redesign of "cntr" circuit.
    - cntr/cntr.pro: added usb_a_plug.lib, mmcx-f-edge.mod, usb_a_plug_smt.mod,
    and sot-323.mod
    - cntr/cntr.sch, cntr/cntr.brd: reassigned LED and pull GPIO for easier
    routing
    - cntr/cntr.sch, cntr/cntr.brd: replaced mini-USB receptacle with USB A
    plug and removed 0 Ohm resistor previously used for swapping D+/D-
    - cntr/cntr.sch, cntr/cntr.brd: changed TVSs on USB from 200 pF 0603 to
    100 pF 0402 type
    - cntr/cntr.sch, cntr/cntr.brd: replaced basically unterminated 100 mil
    header with properly terminated MMCX connector
    - cntr/cntr.brd: reduced board width (nominally 15.8 mm) to USB connector
    width (16 mm)
    - modules/mmcx-f-edge.fpd: swap contacts for co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
    [cntr.brd, cntr.sch]
2010-10-25 Cleaned up board outline and ground routing.
    - cntr/cntr.pro, cntr/cntr.brd: reduced PCB edge line width from 15 mil to
    5 mil
    - cntr/cntr.brd: make edge follow hole for MMCX connector
    - cntr/cntr.brd: fill bottom and input area with ground
    - cntr/cntr.sch, cntr/cntr.brd (R4): replace 0 Ohm jumper and GND via
    P2.1 with vias
    [cntr.brd, cntr.sch]
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2010-10-25 Corrected MMCX connector fields.
    - cntr/cntr.sch: footprint is MMCX-F-EDGE*, not MMCX-F-PLUG*
    - cntr/cntr.sch: changed value from BNC to MMCX
    [cntr.sch]
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2010-11-05 Document that the input circuit does not reach the design frequency (3 MHz) yet.
    - cntr/cntr.sch: added warning that input circuit isn't good enough yet
    - cntr/README: document input circuit problem, with measurement results
    [cntr.sch]
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2010-11-05 More detailed examination of the input circuit problem.
    - cntr/README, ecn/INDEX, ecn/ecn0006.txt: moved discussion of the input
    circuit from README to ECN0006
    - cntr/cntr.sch: changed pointer from README to ECN0006
    - ecn/ecn0006.txt: added more measurements, explanations, and an analysis
    of the situation
    [cntr.sch]
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2010-11-06 cntr/: version 3 with simplified input circuit.
    - cntr/cntr.sch: change input circuit according to ECN0006
    - cntr/cntr.sch: make P2_0 yet another version ID input
    - cntr/cntr.cmp: surprise, this wasn't checked in either
    - cntr/cntr.brd: update for above changes
    - cntr/cntr.brd: adjust for resized USB connector
    - cntr/cntr.brd: top ground fill was very spotty - removed it
    - cntr/cntr.brd: board can now be 100 mil shorter
    - cntr/cam/pcb.pl: updated for new board outline
    [cntr.brd, cntr.sch]
2010-11-06 Updated cntr.sch for BOM processing. Fixed omission in atrf.sub
    - cntr/cntr.sch (P5, P6, P7): added footprint
    - cntr/cntr.pro: commit noise
    - bom/atrf.sub: accept resistor values without unit or multiplier (e.g.,
    "68" becomes "68R")
    [cntr.sch]
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2010-11-06 Minor CNTR layout cleanup.
    - cntr.brd: added pin 1 marker for U1
    - cntr.brd: moved via next to P7 a 5 mil away from the probe trace
    - cntr.pro: commit noise
    [cntr.brd]
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2010-11-11 atusd firmware now supports setting the TST pin.
    - common/io.h: TST is connected to P0_7
    - include/at86rf230.h: added test mode registers REG_CONT_TX_0 (0x36) and
    REG_CONT_TX_1 (0x3d), with their values
    - atspi/atspi.c (set_test_mode): set or reset TST and the LED
    - atspi/atspi.c (reset_rf): leave test mode
    - atspi/atspi.c (test_mode): enter test mode
    - atspi/atspi.c (main): flash the LED when in test mode
    - include/atspi/ep0.h (enum atspi_requests), atspi/ep0.c (my_setup): new
    command ATSPI_TEST to enter test mode
    - include/atspi/ep0.h (EP0ATSPI_MINOR): bumped protocol to version 0.1
    - include/at86rf230.h: corrected comment before TRX_CMD field to indicate
    that the register is called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
    [at86rf230.h, ep0.c, io.h]
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2010-11-11 atusb.sch: mention that the TST connection is a rework and not in the layout
    [atusb.sch]
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2010-11-30 atusb: remove test points from MCU-RF interconnect
    - atusb.sch: removed test points for signals going between USB and RF side
    - atusb.sch: TST is no longer a rework item - removed comment saying it is
    - atusb.sch, usb.sch, atrf.sch: bumped version number to 100930
    [atrf.sch, atusb.sch, usb.sch]
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2010-11-30 atusb: switch from mini-USB receptacle to full-size USB plug
    This way, we can plug the device into a USB port, like a USB stick.
    We use a real plug (instead of shaping the PCB in the form of a plug)
    for better mechanical stability.
    - atusb.pro: change from components/mini_usb_b to components/usb_a_plug
    - usb.sch (CON1): replace MINI_USB_B with USB_A_PLUG
    [usb.sch]
2010-11-30 atusb: use Johanson 2450FB15L0001 instead of discrete balun circuit
    - components/balun-smt6.lib: balun using all six contacts (for Johanson
    2450FB15L0001)
    - components/INFO: added balun-smt6.lib
    - components/INFO (balun): added BOOKSHELF reference (to "748421245")
    - AUTHORS: added forgotten balun.lib and new balun-smt6.lib
    - atrf.sch: replaced discrete balun with integrated balun
    - atrf.sch (C3): replaced output DC block with 0R resistor
    [atrf.sch, usb.sch]
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2010-11-30 atusb: use 0402 as the preferred component size and replace bad TVS
    We know from CNTR that the capacitance of the 0603 TVS (EPCOS CT0603M4G,
    200 pF) is too large and can disturb the USB signal. The 0402 TVS
    (Panasonic EZJ-P0V080GA, 100 pF) works much better.
    Since we have lots of 0402 components already, just change the remaining
    0603 to 0402, too.
    - usb.sch (VR1, VR2, VR3): change from 0603 to 0402 and from 5V5 to 5V6
    - usb.sch (C1, C2, R1): change from 0603 to 0402
    - atrf.sch (R3): set footprint to 0402
    - atusb.pro: replaced modules/mini-usb with modules/usb_a_plug
    - atusb.pro: removed extension from components/balun-smt6.lib
    - atusb.cmp: update footprints for above changes
    - atusb.cmp: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
    [atrf.sch, usb.sch]
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2010-12-01 atusb: remove two unnecessary test points
    - atrf.sch (P15): removed TST test point
    - usb.sch (P10): removed nSYSCLK test point
    - atusb.sch: commit noise
    [atrf.sch, atusb.sch, usb.sch]
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2010-12-02 atusb: rearrange I/Os for new layout
    - usb.sch: rotated and reordered TST, nRST_RF, SLP_TR, SCLK, MISO, MOSI,
    and nSS for new layout
    - atrf.sch: commit noise
    [atrf.sch, usb.sch]
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2010-12-18 atusb: firmware update for the 2010-12-16 board series
    - fw/Makefile: replaced "make" with $(MAKE) (just for style)
    - common/Makefile.common: Makefile settings shared within project. For now,
    this contains only the board version, which defaults to 2010-12-16.
    - fw/common/Makefile, fw/boot/Makefile, fw/atusb/Makefile: include
    common/Makefile.common
    - fw/common/Makefile, fw/boot/Makefile, fw/atusb/Makefile: pass board
    version to cpp and gcc
    - fw/atusb/atusb.c (init_io): individually set IRQ_RF to one, LED and TST
    to zero
    - fw/atusb/atusb.c (init_io): added macros to set all unused pins to zero
    in a way that doesn't need updating if a signal moves from one pin to
    another
    - include/a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
    [atusb.c, io.h]
2010-12-18 atusb.brd: avoid track leaving pad 16 of U2 laterally, for better solderability
    [atusb.brd]
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2010-12-18 atusb.brd: several small solderability improvements
    - atusb.brd: reduced RF front ground area to avoid interconnections very
    close to the chip
    - atusb.brd: reduced RF power front ground area to avoid interconnections
    very close to the chip
    - atusb.brd: moved via next to TXRX pad 18 (GND) to make room for making
    CLK trace leave the pad at its end, not at its side
    - atusb.brd: bumped design date to 20101217
    [atusb.brd]
2010-12-19 atusb: more small layout improvements
    - atusb.brd: increase clearance between RF clock front ground area and MCU
    (ground area acted as solder trap)
    - atusb.brd: route nRST_RF trace out of corner (to avoid accidental
    contact)
    - atusb.brd: don't route VBUS corner trace underneat chip (for general
    tidiness)
    - atusb.brd: bumped version to 20101219
    [atusb.brd]
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2010-12-29 atusb.brd: increased zone clearance from 8 mil to 10 mil, for solderability
    [atusb.brd]
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2010-12-29 atusb.brd: reduced XTAL front ground to shorted "tongue" between pads 24 and 25
    [atusb.brd]
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2010-12-30 atusb.brd: moved via and bumped version number
    - atusb.brd: moved nRST_RF MCU-side via away from SLP_TR via, to avoid
    accidental solder bridges
    - atusb.brd: increased version number to 20101230
    [atusb.brd]
2011-01-02 atusb.brd: increased RF ground zone
    - atusb.brd: increased RF ground zone by 150 mil in an attempt to reduce
    interferences between the the antenna and the rest of the circuit
    - atusb.brd: added more vias around and inside the RF ground zone
    - atusb.brd: set version to 20110102
    [atusb.brd]
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2011-01-04 atusb: switched from the AT86RF230 to the AT86RF231, added missing RF ground
    - atrf.sch: replaced the AT86RF230 with the AT86RF231
    - atusb.sch, usb.sch, atrf.sch: removed TST signal
    - atrf.sch: grounded former TST pin
    - atusb.brd: updated for TST removal
    - atusb.brd: increased space between SLP_TR and nRST_RF vias
    - atusb.brd: connect U2 pin 6 to ground pad
    - atusb.sch, usb.sch, atrf.sch, atusb.brd: changed version to 20110104
    [atrf.sch, atusb.brd, atusb.sch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]
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2011-01-04 atusd: switched to Johanson 2450FB15L0001 balun
    - atusd.pro: changed ../components/balun to ../components/balun-smt6
    - atusd.sch (B1): replaced Wuerth 748421245 with less expensive Johanson
    2450FB15L0001
    [atusd.sch]
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2011-01-04 atusd.brd: increased via density in RF areas
    - atusd.brd: moved antenna by 20 mil to make more room for vias
    - atusd.brd: increased RF via density to up to 50-60 mil per via
    - atusd.brd: increased zone clearance to 10 mil, to make board easier to
    solder
    [atusd.brd]
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2011-01-07 atusb/fw/include/at86rf230.h: many corrections, some additions
    - at86rf230.h (REG_BATMON): address is 0x11, not 0x10
    - at86rf230.h (TRX_CMD_MASK): width is 5 bits, not 3
    - at86rf230.h (CLKM_CTRL_MASK): width is 3 bits, not 2
    - at86rf230.h (PA_EXT_EN, IRQ_2_EXT_EN, TX_AUTO_CRC_ON_231): shifted by one
    bit
    - at86rf230.h (RX_BL_CTRL, AACK_DIS_ACK): added missing field
    - at86rf230.h: added fields PA_BUF_LT and PA_LT
    - at86rf230.h (ANT_DIV): added fields of this register
    - at86rf230.h (NATMON_VTH_SHIFT, NATMON_VTH_MASK): corrected typo
    [at86rf230.h]
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2011-01-15 atusd: use crystal instead of trying to obtain an external clock from the Ben
    Known bug: didn't connect SLP_TR.
    - atusd.sch, atusd.brd: replaced external clock with crystal
    - atusd.sch, atusd.brd: increased version number to 20110115
    - atusd.brd: changed "ATUSD" text on PCB to "8:10 CARD"
    [atusd.brd, atusd.sch]
2011-01-15 atusd: added missing connection for SLP_TR
    - atusd.sch, atusd.brd: connect SLP_TR to MMC CLK (PD09)
    - atusd.brd: changed text "WPAN" to "802.15.4"
    [atusd.brd, atusd.sch]
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2011-01-22 atusb: replaced old chip components with updated ones
    - atusb.brd, atusb.cmp: changed all 0402-M to the new 0402
    - atusb.brd, atusb.cmp: changed 0603-M to the new 0603
    - atusb.brd: updated layout for component changes
    [atusb.brd]
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2011-01-23 atben, atusb: set solder mask and solder paste clearances to NXP's values
    Settings according to
    http://www.nxp.com/documents/mounting_and_soldering/AN10365.pdf
    - atben.pro, atben.brd, atusb.pro, atusb.brd: set solder mask clearance
    to 50 um (copper-defined pads)
    - atben.pro, atben.brd, atusb.pro, atusb.brd: set solder paste clearance
    to 25 um
    [atben.brd, atusb.brd]
2011-01-23 atben.brd: updated balun footprint, some small touch-ups
    - atben.brd: updated 0805-6 footprint of the balun and rearranged its
    surroundings accordingly
    - atben.brd: rearranged boundary between RF and power ground zones
    - atben.brd: moved vias "south" of the balun by 5 mil
    - atben.brd: moved component references C10, C11, and X1 such that
    they're not convered by comment lines
    - atben.brd: broke up comment line "east" of X1 to avoid overlap with C10
    and C11 pads
    - atben.brd: shifted author's name to make crossing lines coincide with
    vertical strokes in letters
    [atben.brd]
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2011-01-28 atusb: replaced the C8051F326 with an ATmega32U2 (still needs cleanup)
    - atusb.pro (LibName5): changed from c8051f326 to atmega8u2
    - atrf.sch: export CLKM and added filter for 8 MHz clock
    - atusb.sch: connect CLK between RF and USB side
    - usb.sch: changed design frim C8051F326 to ATmega32U2 (needs cleanup)
    [atrf.sch, atusb.sch, usb.sch]
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
